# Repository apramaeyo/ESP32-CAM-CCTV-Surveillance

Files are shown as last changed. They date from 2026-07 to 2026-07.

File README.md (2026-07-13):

# ESP32-CAM-CCTV-Surveillance
Dual-axis pan/tilt CCTV system with live MJPEG streaming, night vision, motion detection and web control - built on ESP32-CAM

## Features

- Live MJPEG streaming
- Pan/Tilt camera control
- Auto patrol mode
- Software motion detection
- Automatic IR night vision
- Battery powered
- Custom PCB
- 3D printed casing

## Hardware

- ESP32-CAM
- MG90S Servos
- LDR
- 850/940nm IR LEDs
- 2×18650 Battery
- DC-DC Buck converter
- ESP32 CAM MB/FTDI MODULE

## Software

- Arduino IDE
- C/C++
- HTML/CSS/JavaScript

## Demo videos (click to view)

ESP32-CAM CCTV Demo 1 (https://youtu.be/uphCyD1VkAQ)

ESP32-CAM CCTV Demo 2 (https://youtu.be/F1fGy5tqCIQ)

ESP32-CAM CCTV Demo 3 (https://youtu.be/pY-STUEJHV8)

ESP32-CAM CCTV Demo 4 (https://youtu.be/E-zW0o_Lmso)

### Finished Project

Finished Project

### Live Web Interface

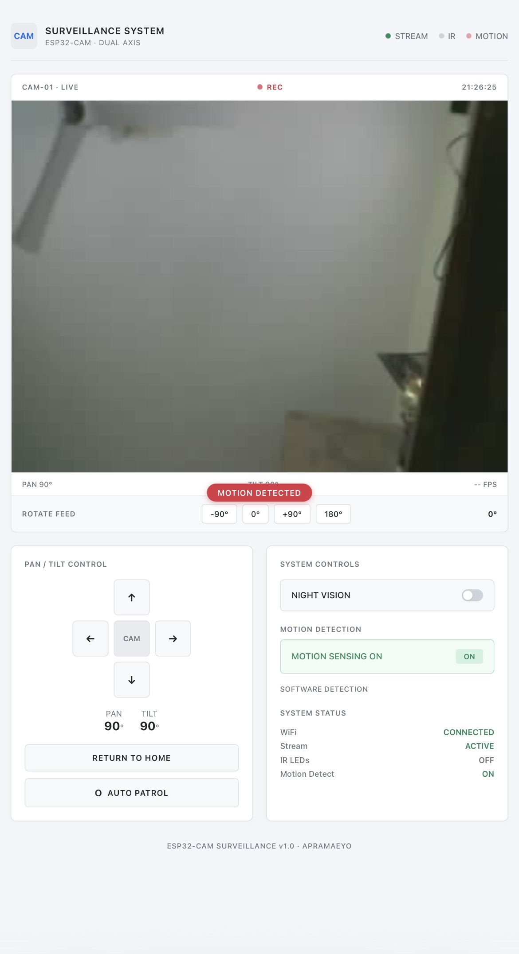
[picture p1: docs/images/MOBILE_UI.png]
Web UI


### PCB Design

PCB

### Night Vision Circuit

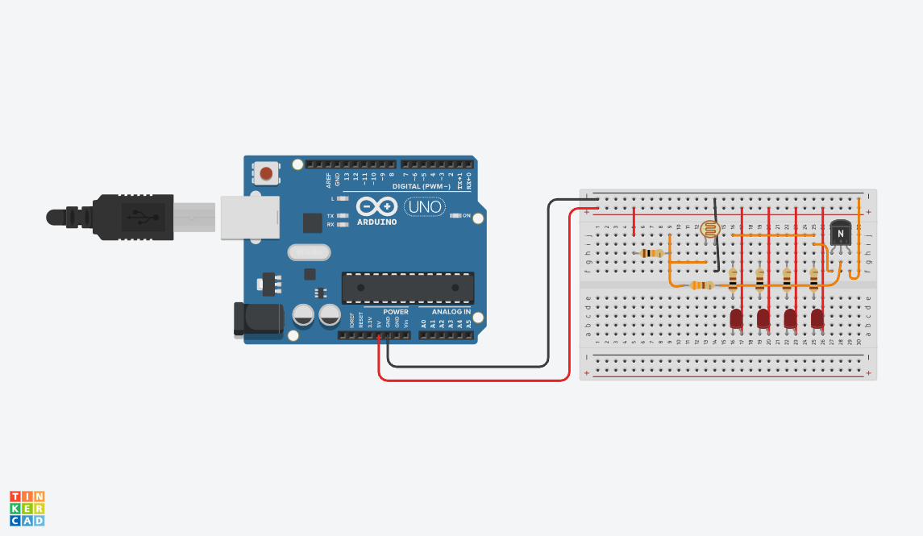
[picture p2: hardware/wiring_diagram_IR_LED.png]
Night Vision


## Future Improvements

- Telegram notifications
- Face detection
- Mobile application
- Cloud recording

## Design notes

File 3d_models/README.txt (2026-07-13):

ESP32CAM PANTILT CASE by Shubhayu15k on Thingiverse: https://www.thingiverse.com/thing:6805012

Summary:
This custom-designed case is perfect for housing your ESP32-CAM with a pan and tilt mechanism. Built for makers and hobbyists, this compact case ensures protection and stability for your camera module while allowing full range of motion with servo-controlled panning and tilting. Ideal for surveillance, robotics, or any project requiring camera movement, the case offers easy access to wiring and mounting points for servos.Key Features:Compact Design: Fits the ESP32-CAM module snugly.Servo Compatibility: Supports most micro servos for pan and tilt control.Ventilation Slots: Prevents overheating during extended use.Easy Assembly: Snap-fit design with screws for secure closure.Customizable Mounting: Features multiple holes for flexible mounting options.Clean Aesthetics: Sleek design that blends well with any project setup.This 3D-printed case makes your ESP32-CAM project more durable and organized, ensuring smooth camera operation in a range of applications!

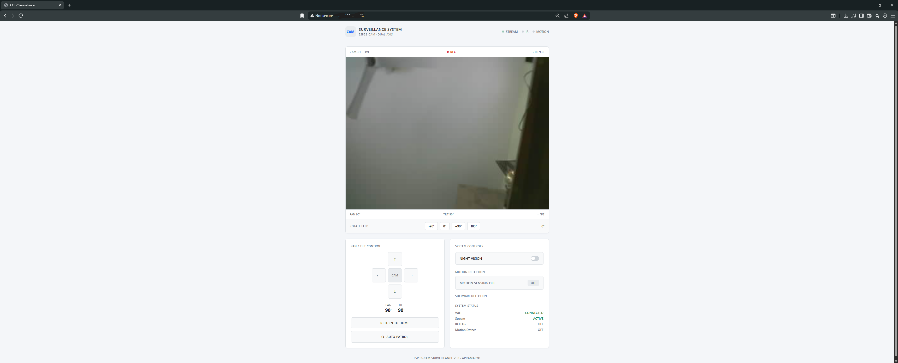
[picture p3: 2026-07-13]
docs/images/WEB_UI.png

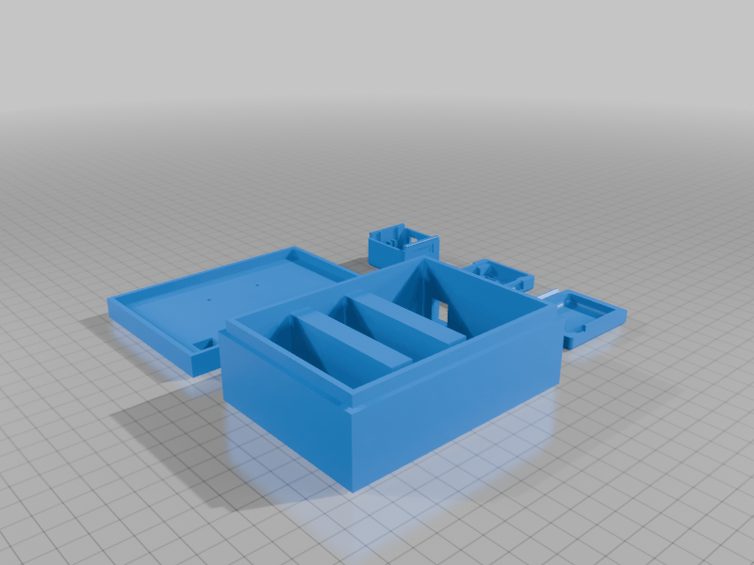
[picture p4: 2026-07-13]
3d_models/boxfinalesp32cam.png

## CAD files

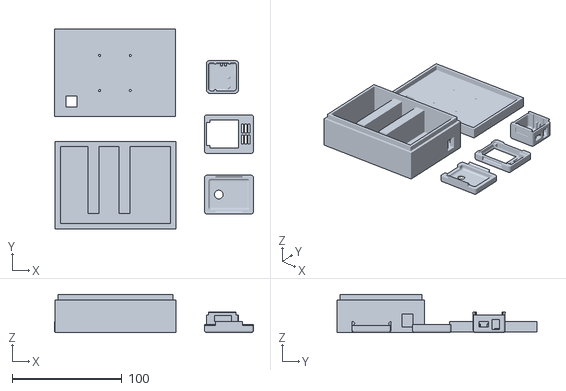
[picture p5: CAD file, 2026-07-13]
3d_models/boxfinalesp32cam.stl
181.1 x 181.9 x 35.0

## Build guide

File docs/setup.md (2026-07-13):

# Setup Guide — ESP32-CAM Dual-Axis CCTV Surveillance System

## Table of Contents

1. [Hardware Required](#hardware-required)
2. [Wiring](#wiring)
3. [Software Setup](#software-setup)
4. [Configuration](#configuration)
5. [Flashing](#flashing)
6. [Usage](#usage)
7. [3D Printing](#3d-printing)
8. [PCB](#pcb)
9. [Troubleshooting](#troubleshooting)

\---

## Hardware Required

|Component|Qty|Notes|
|-|-|-|
|AI Thinker ESP32-CAM (OV3660)|1|Main controller + camera|
|MG90S Metal Gear Servo|2|Pan + Tilt|
|Pan-Tilt Bracket|1|Standard SG90/MG90S compatible|
|HC-SR501 PIR Sensor|1|Optional — for hardware motion detect|
|850/940nm IR LED 5mm|4|Night vision|
|LDR (Light Dependent Resistor)|1|Auto night vision switching|
|2N2222A NPN Transistor (TO-92)|1|IR LED switching|
|330Ω Resistor 1/4W|1|Transistor base resistor|
|100Ω Resistor 1/4W|4|IR LED current limiters|
|10kΩ Resistor 1/4W|1|LDR voltage divider|
|LM2596S Buck Converter|1|Set output to 5V|
|18650 Battery Holder (2 cell)|1|With ON/OFF switch|
|18650 Battery 3.7V|2|Recommended: 2600mAh+|
|FTDI FT232RL / ESP32-CAM-MB|1|For flashing only|
|Jumper Wires|—|Male-to-female|
|Zero PCB / Perfboard|1|For IR LED circuit|

\---

## Wiring

### Power

```
18650 Pack (+) → LM2596S IN+
18650 Pack (−) → LM2596S IN−
LM2596S OUT+    → ESP32-CAM 5V
LM2596S OUT+    → Pan servo VCC 
LM2596S OUT+    → Tilt servo VCC 
LM2596S OUT−    → ESP32-CAM GND
LM2596S OUT−    → Pan servo GND 
LM2596S OUT−    → Tilt servo GND 
```

> ⚠️ Set LM2596S output to exactly 5.0V before connecting anything

### Servos

```
Pan  servo signal  → GPIO 14
Tilt servo signal  → GPIO 15
```

### IR LED Circuit (LDR auto-switching)

```
5V ──[10kΩ]──┬──[330Ω]──→ 2N2222 BASE (middle leg)
             │
           [LDR]
             │
            GND

2N2222 EMITTER (left leg)    → GND
2N2222 COLLECTOR (right leg) → 4× [100Ω] → IR LED (+)
                                             IR LED (−) → GND
```

### 2N2222 Pinout (flat face toward you, legs down)

```
Left = Emitter | Middle = Base | Right = Collector
```

### GPIO Summary

```
GPIO 4  → IR LED / Onboard flash LED
GPIO 14 → Pan servo signal
GPIO 15 → Tilt servo signal
```

\---

## Software Setup

### 1\. Install Arduino IDE

Download from [arduino.cc](https://www.arduino.cc/en/software)

### 2\. Add ESP32 Board Support

* Open Arduino IDE
* Go to **File → Preferences**
* Add to Additional Board Manager URLs:

```
https://dl.espressif.com/dl/package_esp32_index.json
```

* Go to **Tools → Board → Boards Manager**
* Search `esp32` → Install **esp32 by Espressif Systems**

### 3\. Install Libraries

Go to **Sketch → Include Library → Manage Libraries**

|Library|Author|
|-|-|
|ESP32Servo|Kevin Harrington|

### 4\. Select Board

**Tools → Board → AI Thinker ESP32-CAM**

\---

## Configuration

Open `firmware/ESP32_CAM_Surveillance.ino` and edit these lines at the top:

```cpp
// WiFi credentials
const char* WIFI_SSID = "YOUR_WIFI_NAME";
const char* WIFI_PASS = "YOUR_WIFI_PASSWORD";

// Static IP — change to match your network
// Find your gateway: Windows CMD → ipconfig → Default Gateway
IPAddress STATIC_IP(192, 168, 1, 100);  // ← pick any free IP
IPAddress GATEWAY  (192, 168, 1,   1);  // ← your router IP
IPAddress SUBNET   (255, 255, 255,  0);  // ← leave this
IPAddress DNS      (  8,   8,   8,  8);  // ← leave this
```

> Example: if your gateway is 192.168.108.1 → use 192.168.108.150 for STATIC_IP

\---

## Flashing

### Using FTDI Module

```
FTDI GND → ESP32-CAM GND
FTDI 5V  → ESP32-CAM 5V
FTDI TX  → ESP32-CAM U0R
FTDI RX  → ESP32-CAM U0T
GPIO 0   → GND  (boot mode — only during flashing)
```

1. Connect GPIO 0 to GND
2. Power on
3. Click Upload in Arduino IDE
4. When you see `Connecting......` — press RESET button on ESP32-CAM
5. After upload — disconnect GPIO 0 from GND
6. Press RESET
7. Open Serial Monitor at **115200 baud**
8. You will see:

```
━━━━━━━━━━━━━━━━━━━━━━━━━━━━━━━━━━━
  BOOKMARK THIS URL: http://192.168.1.100
  This IP will NEVER change.
━━━━━━━━━━━━━━━━━━━━━━━━━━━━━━━━━━━
```

### Using ESP32-CAM-MB

Just plug in via USB — no extra wiring needed. GPIO 0 handled automatically.

\---

## Usage

Open the IP address in any browser on the same WiFi network.

### Web UI Features

|Button|Function|
|-|-|
|▲ ▼ ◀ ▶|Pan and tilt camera|
|⌂ RETURN TO HOME|Snap back to 90°/90°|
|↻ AUTO PATROL|Continuous left-right sweep|
|NIGHT VISION|Toggle IR LED/inbuilt LED (GPIO 4)|
|MOTION DETECT|Enable/disable software motion detection|
|↺ ⊙ ↻ ↕|Rotate live feed 90°/180°/270° in browser|

### Motion Detection

When motion is detected:

* MOTION DETECTED banner appears on live feed
* Red dot pulses in header
* Clears automatically after 3 seconds of no motion

### Night Vision

* Manual: press button on web UI
* Automatic (if LDR circuit installed): hardware controlled, no button needed

\---

## 3D Printing

Files in `3d_models` folder.

### Print Settings

```
Material : PLA
Layer    : 0.2mm
Infill   : 25-30%
Walls    : 3-4 perimeters
Supports : Yes for elec_base only
```

\---

## Troubleshooting

|Problem|Cause|Fix|
|-|-|-|
|Stream not loading|Wrong IP or not on same WiFi|Check Serial Monitor for IP|
|Camera init failed|Bad 5V supply or loose ribbon|Check LM2596S output = 5V, reseat ribbon|
|Servos jitter|Insufficient current|Connect servo power direct to LM2596S, not through breadboard|
|Only one servo moves|Wrong GPIO|Confirm GPIO 14 = pan, GPIO 15 = tilt|
|IR LED not glowing|2N2222 orientation wrong|Flat face toward you: left=E, mid=B, right=C|
|No WiFi connection|Wrong credentials or 5GHz network|ESP32 only supports 2.4GHz|
|Website laggy|WiFi power saving enabled|Already disabled in firmware — check router distance|
|Motion too sensitive|Lighting changes triggering|Increase `MOTION_THRESHOLD` value in code|
|IP keeps changing|DHCP reassigning|Static IP already configured — check GATEWAY matches your router|

\---

## License

MIT License — free to use, modify, and distribute with attribution.

\---

*Built by Apramaeyo*

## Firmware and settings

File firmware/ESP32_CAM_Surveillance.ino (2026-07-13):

/*
 * ============================================================
 *  Dual-Axis CCTV Surveillance System
 *  Hardware : ESP32-CAM (AI Thinker)
 *  Features : Live MJPEG stream, Pan/Tilt servos,
 *             Motion detection, IR LED night vision
 *  Control  : Web browser over WiFi
 * ============================================================
 *
 *  WIRING SUMMARY
 *  ──────────────
 *  Pan  Servo  signal → GPIO 14   
 *  Tilt Servo  signal → GPIO 15   
 *  Both Servo  VCC   → 5V rail from buck converter
 *  Both Servo  GND   → Common GND
 *
 *  IR LED circuit:
 *    GPIO 4 → 330Ω resistor → Base of 2N2222
 *    Collector → IR LED anode
 *    IR LED cathode → GND
 *    Emitter → GND
 *  (GPIO 4 is also the onboard white flash LED — it will light
 *   up instead if you don't have IR LEDs yet, useful for testing)
 *
 *  Power:
 *    18650 pack → LM2596S → 5V → ESP32-CAM 5V pin + Servo VCC
 *    Common GND between all components
 *
 *  FLASHING INSTRUCTIONS
 *  ─────────────────────
 *  1. Install board: "AI Thinker ESP32-CAM" in Arduino IDE
 *     (add https://dl.espressif.com/dl/package_esp32_index.json
 *      to Preferences → Additional board manager URLs)
 *  2. Install library: ESP32Servo (by Kevin Harrington)
 *  3. Connect GPIO 0 to GND before powering on (boot mode)
 *  4. Select: Tools → Board → AI Thinker ESP32-CAM
 *             Tools → Port → your COM port
 *  5. Upload, then disconnect GPIO 0 from GND, press RESET
 *  6. Open Serial Monitor at 115200 baud to see the IP address
 *  7. Open that IP in your browser
 * ============================================================
 */

#include "esp_camera.h"
#include <WiFi.h>
#include <WebServer.h>
#include <ESP32Servo.h>
#include "esp_wifi.h"       // for esp_wifi_set_ps()

// ─── WiFi credentials ────────────────────────────────────────
const char* WIFI_SSID = "WIFISSID";
const char* WIFI_PASS = "WIFIPASSWORD";

// ─── Static IP configuration ─────────────────────────────────
// Change these to match your home network.
// STATIC_IP  = the fixed address you want ESP32-CAM to always use
// GATEWAY    = your router IP (usually 192.168.1.1 or 192.168.0.1)
// SUBNET     = almost always 255.255.255.0
//
// HOW TO FIND YOUR GATEWAY:
//   Windows: open CMD → type "ipconfig" → look for "Default Gateway"
//   Android: WiFi settings → tap network → Gateway
//   After finding gateway, set STATIC_IP to same first 3 numbers
//   e.g. gateway = 192.168.1.1  →  use 192.168.1.XXX for static IP
//   Pick XXX between 100-200 to avoid conflicts with other devices
//
IPAddress STATIC_IP(192, 168, 1, XX);   // ← your chosen fixed IP
IPAddress GATEWAY  (192,168,1,XX);   // ← your router IP
IPAddress SUBNET   (255, 255, 255, 0);   // ← leave this as is
IPAddress DNS      (8,   8,   8,   8);   // ← Google DNS, leave as is

// ─── Pin definitions ─────────────────────────────────────────
#define PAN_PIN   14   // Pan servo signal
#define TILT_PIN  15   // Tilt servo signal
#define IR_PIN     4   // GPIO 4 = onboard white flash LED

// ─── Servo angle limits ──────────────────────────────────────
#define PAN_MIN   0
#define PAN_MAX   180
#define PAN_HOME  90
#define TILT_MIN  90
#define TILT_MAX  180
#define TILT_HOME 90
#define STEP      15    // target degrees per button press

// ─── Smooth servo motion config ──────────────────────────────
// Servos move via easing — accelerate, cruise, decelerate
// like a real camera gimbal. No more sudden jumps.
float panCurrent   = 90.0;   // actual current position (float for smooth steps)
float tiltCurrent  = 90.0;
float panTarget    = 90.0;   // where we want to go
float tiltTarget   = 90.0;
const float EASE_SPEED   = 0.10;  // 0.0-1.0: higher = faster/snappier
                                   // 0.10 = very smooth/slow
                                   // 0.18 = smooth but responsive  
                                   // 0.30 = fast, slight smoothing
                                   // 1.0  = instant (no easing)
const float DEAD_ZONE    = 0.4;   // stop moving when this close to target (degrees)

// ─── AI Thinker ESP32-CAM pins (OV3660 sensor variant) ──────
#define PWDN_GPIO_NUM     32
#define RESET_GPIO_NUM    -1
#define XCLK_GPIO_NUM      0
#define SIOD_GPIO_NUM     26
#define SIOC_GPIO_NUM     27
#define Y9_GPIO_NUM       35
#define Y8_GPIO_NUM       34
#define Y7_GPIO_NUM       39
#define Y6_GPIO_NUM       36
#define Y5_GPIO_NUM       21
#define Y4_GPIO_NUM       19
#define Y3_GPIO_NUM       18
#define Y2_GPIO_NUM        5
#define VSYNC_GPIO_NUM    25
#define HREF_GPIO_NUM     23
#define PCLK_GPIO_NUM     22

// ─── Global state ────────────────────────────────────────────
Servo panServo;
Servo tiltServo;
WebServer server(80);

// panAngle/tiltAngle now track TARGET (int for JSON/display)
// Actual smooth position tracked by panCurrent/tiltCurrent (float)
int panAngle  = PAN_HOME;
int tiltAngle = TILT_HOME;
bool irOn          = false;
bool motionDetected = false;

// Software motion detection — frame differencing
uint8_t* prevFrame = nullptr;
const int MOTION_THRESHOLD = 40;   // pixel difference to count
const int MOTION_PIXELS    = 500;  // how many changed pixels = motion

// ─── Embedded Web UI ─────────────────────────────────────────
const char HTML_PAGE[] PROGMEM = R"rawhtml(
<!DOCTYPE html>
<html lang="en">
<head>
<meta charset="UTF-8">
<meta name="viewport" content="width=device-width, initial-scale=1.0">
<title>CCTV Surveillance</title>
<style>
  :root {
    --bg: #f4f6f9;
    --panel: #ffffff;
    --border: #dee2e6;
    --accent: #0d6efd;
    --accent-hover: #0b5ed7;
    --text: #212529;
    --text-dim: #6c757d;
    --green: #198754;
    --red: #dc3545;
  }
  
  * { box-sizing: border-box; margin: 0; padding: 0; }
  
  body {
    background: var(--bg);
    color: var(--text);
    font-family: -apple-system, BlinkMacSystemFont, "Segoe UI", Roboto, Helvetica, Arial, sans-serif;
    min-height: 100vh;
    display: flex;
    flex-direction: column;
    align-items: center;
    padding: 20px 16px;
    gap: 20px;
  }

  /* ── Header ── */
  header {
    width: 100%;
    max-width: 780px;
    display: flex;
    align-items: center;
    justify-content: space-between;
    border-bottom: 1px solid var(--border);
    padding-bottom: 16px;
  }
  .logo {
    display: flex;
    align-items: center;
    gap: 12px;
  }
  .logo-icon {
    width: 40px; height: 40px;
    background: #e9ecef;
    border-radius: 8px;
    display: flex; align-items: center; justify-content: center;
    font-size: 13px;
    font-weight: 700;
    color: var(--accent);
  }
  .logo-text { font-size: 14px; font-weight: 600; letter-spacing: 0.05em; color: var(--text); }
  .logo-sub  { font-size: 11px; color: var(--text-dim); letter-spacing: 0.05em; margin-top: 2px;}
  .status-bar {
    display: flex; gap: 16px; font-size: 12px; font-weight: 500; color: var(--text-dim);
  }
  .status-item { display: flex; align-items: center; gap: 6px; }
  .dot {
    width: 8px; height: 8px; border-radius: 50%;
    background: var(--green);
    animation: pulse 2s infinite;
  }
  .dot.off { background: #ced4da; animation: none; }
  .dot.alert { background: var(--red); }
  @keyframes pulse {
    0%,100% { opacity: 1; } 50% { opacity: 0.4; }
  }

  /* ── Stream panel ── */
  .stream-panel {
    width: 100%;
    max-width: 780px;
    background: var(--panel);
    border: 1px solid var(--border);
    border-radius: 8px;
    overflow: hidden;
    position: relative;
    box-shadow: 0 2px 4px rgba(0,0,0,0.02);
  }
  .stream-header {
    display: flex;
    justify-content: space-between;
    align-items: center;
    padding: 12px 16px;
    border-bottom: 1px solid var(--border);
    font-size: 11px;
    font-weight: 600;
    letter-spacing: 0.05em;
    color: var(--text-dim);
  }
  .rec-badge {
    display: flex; align-items: center; gap: 6px;
    color: var(--red); font-weight: 700;
  }
  .rec-dot {
    width: 8px; height: 8px; border-radius: 50%;
    background: var(--red);
    animation: pulse 1s infinite;
  }
  
  .motion-overlay {
    position: absolute;
    bottom: 45px; left: 0; right: 0;
    display: flex; justify-content: center;
    pointer-events: none;
  }
  .motion-badge {
    background: var(--red);
    color: #fff;
    padding: 6px 16px;
    border-radius: 20px;
    font-size: 12px;
    font-weight: 600;
    letter-spacing: 0.05em;
    display: none;
    box-shadow: 0 2px 8px rgba(220, 53, 69, 0.4);
  }
  .motion-badge.visible { display: block; }
  .stream-footer {
    padding: 10px 16px;
    display: flex; justify-content: space-between;
    font-size: 11px; font-weight: 500; color: var(--text-dim);
    border-top: 1px solid var(--border);
  }

  /* ── Controls ── */
  .controls-row {
    width: 100%;
    max-width: 780px;
    display: flex;
    gap: 20px;
    flex-wrap: wrap;
  }
  .ctrl-panel {
    background: var(--panel);
    border: 1px solid var(--border);
    border-radius: 8px;
    padding: 20px;
    flex: 1;
    min-width: 280px;
    box-shadow: 0 2px 4px rgba(0,0,0,0.02);
  }
  .ctrl-label {
    font-size: 11px;
    font-weight: 600;
    letter-spacing: 0.05em;
    color: var(--text-dim);
    margin-bottom: 16px;
    text-transform: uppercase;
  }

  /* D-pad */
  .dpad {
    display: grid;
    grid-template-columns: repeat(3, 54px);
    grid-template-rows: repeat(3, 54px);
    gap: 8px;
    justify-content: center;
  }
  .dpad-btn {
    background: #f8f9fa;
    border: 1px solid var(--border);
    border-radius: 6px;
    color: var(--text);
    font-size: 16px;
    font-weight: bold;
    cursor: pointer;
    display: flex; align-items: center; justify-content: center;
    transition: all 0.15s ease;
    user-select: none;
    -webkit-tap-highlight-color: transparent;
  }
  .dpad-btn:hover {
    background: #e9ecef;
  }
  .dpad-btn:active, .dpad-btn.pressed {
    background: #dde2e6;
    transform: scale(0.95);
  }
  .dpad-center {
    background: #e9ecef;
    color: var(--text-dim);
    font-size: 11px;
    font-weight: 600;
    cursor: default;
  }
  .dpad-center:active { transform: none; }

  /* Angle readout */
  .angle-display {
    margin-top: 16px;
    display: flex; justify-content: center; gap: 24px;
    font-size: 12px; color: var(--text-dim);
    text-align: center;
  }
  .angle-val { color: var(--text); font-size: 18px; font-weight: 700; }

  /* Toggle buttons */
  .toggle-group {
    display: flex; flex-direction: column; gap: 12px;
  }

  .toggle-btn {
    background: #f8f9fa;
    border: 1px solid var(--border);
    border-radius: 6px;
    color: var(--text);
    padding: 14px 16px;
    cursor: pointer;
    font-family: inherit;
    font-size: 13px;
    font-weight: 500;
    display: flex; align-items: center; justify-content: space-between;
    transition: all 0.2s ease;
  }
  .toggle-btn:hover { border-color: var(--accent); }
  .toggle-btn.active {
    border-color: var(--accent);
    background: #f0f7ff;
    color: var(--accent);
  }
  .toggle-indicator {
    width: 32px; height: 18px;
    background: #ced4da;
    border-radius: 10px;
    position: relative;
    transition: background 0.2s;
  }
  .toggle-indicator::after {
    content: '';
    position: absolute;
    width: 14px; height: 14px;
    border-radius: 50%;
    background: #fff;
    top: 2px; left: 2px;
    transition: transform 0.2s, background 0.2s;
    box-shadow: 0 1px 3px rgba(0,0,0,0.1);
  }
  .toggle-btn.active .toggle-indicator { background: var(--accent); }
  .toggle-btn.active .toggle-indicator::after {
    transform: translateX(14px);
  }

  /* ── Big Motion Detect Button ── */
  .motion-ctrl-wrap {
    margin-top: 20px;
    display: flex;
    flex-direction: column;
    gap: 8px;
  }
  .motion-ctrl-label {
    font-size: 11px;
    font-weight: 600;
    letter-spacing: 0.05em;
    color: var(--text-dim);
    text-transform: uppercase;
  }
  .motion-big-btn {
    width: 100%;
    border: none;
    border-radius: 6px;
    cursor: pointer;
    font-family: inherit;
    padding: 0;
    overflow: hidden;
    position: relative;
    transition: transform 0.1s;
    outline: none;
  }
  .motion-big-btn:active { transform: scale(0.98); }

  /* Inner layout */
  .motion-btn-inner {
    display: flex;
    align-items: center;
    justify-content: space-between;
    padding: 14px 16px;
    transition: all 0.3s ease;
    border: 1px solid transparent;
    border-radius: 6px;
  }

  /* OFF state */
  .motion-big-btn.off .motion-btn-inner {
    background: #f8f9fa;
    border-color: var(--border);
  }
  .motion-big-btn.off .motion-btn-text  { color: var(--text-dim); font-size: 13px; font-weight: 500; }
  .motion-big-btn.off .motion-btn-state {
    background: #e9ecef;
    color: var(--text-dim);
    font-size: 11px;
    font-weight: 600;
    padding: 4px 12px;
    border-radius: 4px;
  }

  /* ON state */
  .motion-big-btn.on .motion-btn-inner {
    background: #f0fdf4;
    border-color: #a3e6cd;
  }
  .motion-big-btn.on .motion-btn-text  { color: var(--green); font-size: 13px; font-weight: 500; }
  .motion-big-btn.on .motion-btn-state {
    background: #d1f2e2;
    color: var(--green);
    font-size: 11px;
    font-weight: 600;
    padding: 4px 12px;
    border-radius: 4px;
  }

  /* Confirm flash overlay */
  .motion-big-btn::after {
    content: '';
    position: absolute;
    inset: 0;
    background: rgba(0,0,0,0.05);
    opacity: 0;
    pointer-events: none;
    transition: opacity 0.15s;
  }
  .motion-big-btn.flash::after { opacity: 1; }

  /* Sensitivity slider */
  .sensitivity-row {
    display: flex;
    align-items: center;
    gap: 12px;
    padding: 8px 4px 4px;
    opacity: 1;
    transition: opacity 0.3s;
  }
  .sensitivity-row.hidden { opacity: 0.3; pointer-events: none; }
  .sens-label { font-size: 12px; font-weight: 500; color: var(--text-dim); white-space: nowrap; }
  .sens-slider {
    flex: 1;
    -webkit-appearance: none;
    height: 4px;
    border-radius: 2px;
    background: #e9ecef;
    outline: none;
    cursor: pointer;
  }
  .sens-slider::-webkit-slider-thumb {
    -webkit-appearance: none;
    width: 16px; height: 16px;
    border-radius: 50%;
    background: var(--accent);
    cursor: pointer;
    transition: background 0.2s;
  }
  .sens-slider::-webkit-slider-thumb:hover { background: var(--accent-hover); }
  .sens-val {
    font-size: 12px;
    font-weight: 600;
    color: var(--text);
    min-width: 24px;
    text-align: right;
  }

  /* Home button */
  .home-btn {
    width: 100%;
    background: #f8f9fa;
    border: 1px solid var(--border);
    border-radius: 6px;
    color: var(--text);
    padding: 12px;
    cursor: pointer;
    font-family: inherit;
    font-size: 12px;
    font-weight: 600;
    letter-spacing: 0.05em;
    margin-top: 16px;
    transition: all 0.2s ease;
  }
  .home-btn:hover { border-color: var(--accent); color: var(--accent); background: #f0f7ff; }

  /* Rotate / patrol button */
  .rotate-btn {
    width: 100%;
    border-radius: 6px;
    padding: 12px;
    cursor: pointer;
    font-family: inherit;
    font-size: 12px;
    font-weight: 600;
    letter-spacing: 0.05em;
    margin-top: 10px;
    border: 1px solid var(--border);
    background: #f8f9fa;
    color: var(--text);
    display: flex;
    align-items: center;
    justify-content: center;
    gap: 8px;
    transition: all 0.2s ease;
  }
  .rotate-btn.spinning {
    border-color: var(--accent);
    color: var(--accent);
    background: #f0f7ff;
  }
  .spin-icon {
    display: inline-block;
    transition: transform 0.3s;
    font-size: 14px;
  }
  .rotate-btn.spinning .spin-icon {
    animation: spinIcon 1.5s linear infinite;
  }
  @keyframes spinIcon {
    from { transform: rotate(0deg); }
    to   { transform: rotate(360deg); }
  }

  /* Stream image rotation */
  .stream-img {
    width: 100%;
    display: block;
    aspect-ratio: 4/3;
    object-fit: cover;
    background: #e9ecef;
    transition: transform 0.4s cubic-bezier(0.4, 0, 0.2, 1);
    transform-origin: center center;
  }
  .stream-img.rot90  { transform: rotate(90deg)  scale(0.75); }
  .stream-img.rot180 { transform: rotate(180deg) scale(1.0);  }
  .stream-img.rot270 { transform: rotate(270deg) scale(0.75); }

  /* Rotate feed button row */
  .feed-rotate-row {
    display: flex;
    align-items: center;
    justify-content: space-between;
    padding: 12px 16px;
    border-top: 1px solid var(--border);
    background: #f8f9fa;
  }
  .feed-rotate-label {
    font-size: 11px;
    font-weight: 600;
    letter-spacing: 0.05em;
    color: var(--text-dim);
  }
  .feed-rotate-btns {
    display: flex;
    gap: 8px;
  }
  .feed-rot-btn {
    background: #ffffff;
    border: 1px solid var(--border);
    border-radius: 4px;
    color: var(--text);
    padding: 6px 12px;
    font-size: 12px;
    font-weight: 500;
    cursor: pointer;
    transition: all 0.15s ease;
    font-family: inherit;
  }
  .feed-rot-btn:hover  { border-color: var(--accent); color: var(--accent); }
  .feed-rot-btn:active { background: #e9ecef; transform: scale(0.95); }
  .feed-rot-btn.active { border-color: var(--accent); color: var(--accent); background: #f0f7ff; font-weight: 600;}
  .rot-angle-badge {
    font-size: 12px;
    font-weight: 600;
    color: var(--text);
    min-width: 30px;
    text-align: right;
  }

  /* Footer */
  footer {
    font-size: 11px;
    font-weight: 500;
    color: var(--text-dim);
    letter-spacing: 0.05em;
    margin-top: 10px;
  }

  @media (max-width: 520px) {
    .status-bar { display: none; }
  }
</style>
</head>
<body>

<header>
  <div class="logo">
    <div class="logo-icon">CAM</div>
    <div>
      <div class="logo-text">SURVEILLANCE SYSTEM</div>
      <div class="logo-sub">ESP32-CAM · DUAL AXIS</div>
    </div>
  </div>
  <div class="status-bar">
    <div class="status-item"><div class="dot" id="streamDot"></div>STREAM</div>
    <div class="status-item"><div class="dot off" id="irDot"></div>IR</div>
    <div class="status-item"><div class="dot off" id="motionDot"></div>MOTION</div>
  </div>
</header>

<!-- Stream -->
<div class="stream-panel">
  <div class="stream-header">
    <span>CAM-01 · LIVE</span>
    <div class="rec-badge"><div class="rec-dot"></div>REC</div>
    <span id="timeDisplay">--:--:--</span>
  </div>
  <img class="stream-img" id="streamImg" src="/stream" alt="Live Feed">
  <div class="motion-overlay">
    <div class="motion-badge" id="motionBadge">MOTION DETECTED</div>
  </div>
  <div class="stream-footer">
    <span>PAN <span id="panReadout">90</span>°</span>
    <span>TILT <span id="tiltReadout">90</span>°</span>
    <span id="fpsDisplay">-- FPS</span>
  </div>
  <div class="feed-rotate-row">
    <span class="feed-rotate-label">ROTATE FEED</span>
    <div class="feed-rotate-btns">
      <button class="feed-rot-btn" onclick="rotateFeed(-90)" title="Rotate left 90°">-90°</button>
      <button class="feed-rot-btn" onclick="rotateFeed(0)"   title="Reset rotation" id="rotResetBtn">0°</button>
      <button class="feed-rot-btn" onclick="rotateFeed(90)"  title="Rotate right 90°">+90°</button>
      <button class="feed-rot-btn" onclick="rotateFeed(180)" title="Flip 180°">180°</button>
    </div>
    <span class="rot-angle-badge" id="rotBadge">0°</span>
  </div>
</div>

<!-- Controls -->
<div class="controls-row">

  <!-- D-pad -->
  <div class="ctrl-panel">
    <div class="ctrl-label">PAN / TILT CONTROL</div>
    <div class="dpad">
      <div></div>
      <div class="dpad-btn" onclick="move('up')"    id="btn-up">↑</div>
      <div></div>
      <div class="dpad-btn" onclick="move('left')"  id="btn-left">←</div>
      <div class="dpad-btn dpad-center">CAM</div>
      <div class="dpad-btn" onclick="move('right')" id="btn-right">→</div>
      <div></div>
      <div class="dpad-btn" onclick="move('down')"  id="btn-down">↓</div>
      <div></div>
    </div>
    <div class="angle-display">
      <div>PAN <br><span class="angle-val" id="panAngle">90</span>°</div>
      <div>TILT<br><span class="angle-val" id="tiltAngle">90</span>°</div>
    </div>
    <button class="home-btn" onclick="goHome()">RETURN TO HOME</button>
    <button class="rotate-btn" id="rotateBtn" onclick="togglePatrol()">
      <span class="spin-icon">O</span>
      <span id="rotateBtnText">AUTO PATROL</span>
    </button>
  </div>

  <!-- Toggles -->
  <div class="ctrl-panel">
    <div class="ctrl-label">SYSTEM CONTROLS</div>
    <div class="toggle-group">

      <button class="toggle-btn" id="irBtn" onclick="toggleIR()">
        <span>NIGHT VISION</span>
        <div class="toggle-indicator"></div>
      </button>

    </div>

    <!-- Big Motion Detect Button -->
    <div class="motion-ctrl-wrap">
      <div class="motion-ctrl-label">MOTION DETECTION</div>

      <button class="motion-big-btn on" id="motionBtn" onclick="toggleMotion()">
        <div class="motion-btn-inner">
          <span class="motion-btn-text" id="motionBtnText">MOTION SENSING ON</span>
          <span class="motion-btn-state" id="motionBtnState">ON</span>
        </div>
      </button>

      <!-- PIR sensor -->
      <div style="font-size:11px; font-weight:500; color:var(--text-dim); margin-top:8px; letter-spacing:0.02em;">
        SOFTWARE DETECTION
      </div>
    </div>

    <div style="margin-top:20px; font-size:12px; font-weight:500; color:var(--text-dim); line-height:1.8;">
      <div style="font-weight:600; font-size: 11px; letter-spacing: 0.05em; margin-bottom: 8px;">SYSTEM STATUS</div>
      <div>
        WiFi <span style="float: right; font-weight: 600; color:var(--green)">CONNECTED</span><br>
        Stream <span style="float: right; font-weight: 600; color:var(--green)">ACTIVE</span><br>
        IR LEDs <span id="irStatus" style="float: right; font-weight: 600; color:var(--text-dim)">OFF</span><br>
        Motion Detect <span id="mdStatus" style="float: right; font-weight: 600; color:var(--green)">ON</span>
      </div>
    </div>
  </div>

</div>
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
void loop() {
  server.handleClient();
  smoothServoTick();
  patrolTick();

  delay(1);
}

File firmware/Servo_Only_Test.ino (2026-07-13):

/*
 * ============================================================
 *  SERVO MOTOR TEST — ESP32-CAM (AI Thinker)
 *  Tests pan + tilt MG90S servos ONLY
 *  No camera, no WiFi, no other components needed
 *
 *  MINIMUM WIRING TO RUN THIS:
 *
 *  Power (from LM2596S set to 5V):
 *    5V rail  →  ESP32-CAM 5V pin
 *    5V rail  →  Both servo VCC 
 *    GND rail →  ESP32-CAM GND pin
 *    GND rail →  Both servo GND 
 *
 *  Pan Servo (horizontal):
 *    Signal  → GPIO 14
 *
 *  Tilt Servo (vertical):
 *    Signal  → GPIO 15
 *
 *  LIBRARY NEEDED:
 *    ESP32Servo by Kevin Harrington
 *    Install via: Sketch → Include Library → Manage Libraries
 *    Search "ESP32Servo" → Install
 * ============================================================
 */

#include <ESP32Servo.h>

#define PAN_PIN   14
#define TILT_PIN  15

Servo panServo;
Servo tiltServo;

// ── Helper: move servo slowly step by step ──────────────────
void slowMove(Servo &servo, int fromAngle, int toAngle, int stepDelay = 15) {
  if (fromAngle < toAngle) {
    for (int a = fromAngle; a <= toAngle; a++) {
      servo.write(a);
      delay(stepDelay);
    }
  } else {
    for (int a = fromAngle; a >= toAngle; a--) {
      servo.write(a);
      delay(stepDelay);
    }
  }
}

void setup() {
  Serial.begin(115200);
  delay(1000);

  Serial.println();
  Serial.println("====================================");
  Serial.println("  SERVO TEST — ESP32-CAM");
  Serial.println("====================================");
  Serial.println();

  // Attach servos
  panServo.attach(PAN_PIN,   500, 2400);
  tiltServo.attach(TILT_PIN, 500, 2400);
  Serial.println("[OK] Servos attached");
  Serial.println("     Pan  → GPIO " + String(PAN_PIN));
  Serial.println("     Tilt → GPIO " + String(TILT_PIN));
  Serial.println();

  // ── TEST 1: Center both servos ──────────────────────────
  Serial.println("TEST 1 — CENTER (both to 90°)");
  panServo.write(90);
  tiltServo.write(90);
  Serial.println("  Both servos → 90° (home position)");
  Serial.println("  Both should be pointing straight ahead");
  delay(2000);

  // ── TEST 2: Pan servo only ──────────────────────────────
  Serial.println();
  Serial.println("TEST 2 — PAN SERVO ONLY (GPIO 14)");
  Serial.println("  Tilt stays at 90° — only pan moves");
  Serial.println();

  Serial.println("  Pan: 90° → 0° (full left)");
  slowMove(panServo, 90, 0);
  delay(800);

  Serial.println("  Pan: 0° → 180° (full right)");
  slowMove(panServo, 0, 180);
  delay(800);

  Serial.println("  Pan: 180° → 90° (back to center)");
  slowMove(panServo, 180, 90);
  delay(1000);

  Serial.println("  [CHECK] Did the pan servo sweep left then right?");
  Serial.println("  If YES → Pan servo working");
  Serial.println("  If NO  → Check GPIO 14 wiring and 5V power");

  delay(2000);

  // ── TEST 3: Tilt servo only ─────────────────────────────
  Serial.println();
  Serial.println("TEST 3 — TILT SERVO ONLY (GPIO 15)");
  Serial.println("  Pan stays at 90° — only tilt moves");
  Serial.println();

  Serial.println("  Tilt: 90° → 150° (tilt up)");
  slowMove(tiltServo, 90, 150);
  delay(800);

  Serial.println("  Tilt: 150° → 30° (tilt down)");
  slowMove(tiltServo, 150, 30);
  delay(800);

  Serial.println("  Tilt: 30° → 90° (back to center)");
  slowMove(tiltServo, 30, 90);
  delay(1000);

  Serial.println("  [CHECK] Did the tilt servo go up then down?");
  Serial.println("  If YES → Tilt servo working");
  Serial.println("  If NO  → Check GPIO 15 wiring and 5V power");

  delay(2000);

  // ── TEST 4: Both together ───────────────────────────────
  Serial.println();
  Serial.println("TEST 4 — BOTH SERVOS TOGETHER");

  Serial.println("  Moving to top-left corner...");
  panServo.write(0);
  tiltServo.write(150);
  delay(1500);

  Serial.println("  Moving to top-right corner...");
  panServo.write(180);
  tiltServo.write(150);
  delay(1500);

  Serial.println("  Moving to bottom-right corner...");
  panServo.write(180);
  tiltServo.write(30);
  delay(1500);

  Serial.println("  Moving to bottom-left corner...");
  panServo.write(0);
  tiltServo.write(30);
  delay(1500);

  Serial.println("  Returning to HOME...");
  panServo.write(90);
  tiltServo.write(90);
  delay(1500);

  // ── TEST 5: Nod and shake ───────────────────────────────
  Serial.println();
  Serial.println("TEST 5 — NOD (tilt) AND SHAKE (pan)");

  Serial.println("  Nodding 3 times (tilt up/down)...");
  for (int i = 0; i < 3; i++) {
    tiltServo.write(115);
    delay(300);
    tiltServo.write(65);
    delay(300);
  }
  tiltServo.write(90);
  delay(500);

  Serial.println("  Shaking 3 times (pan left/right)...");
  for (int i = 0; i < 3; i++) {
    panServo.write(60);
    delay(300);
    panServo.write(120);
    delay(300);
  }
  panServo.write(90);
  delay(500);

  // ── DONE ────────────────────────────────────────────────
  Serial.println();
  Serial.println("====================================");
  Serial.println("  ALL SERVO TESTS COMPLETE");
  Serial.println("====================================");
  Serial.println();
  Serial.println("Both servos now hold at 90° (home).");
  Serial.println();
  Serial.println("RESULTS:");
  Serial.println("  If pan moved  → GPIO 14 wiring correct");
  Serial.println("  If tilt moved → GPIO 15 wiring correct");
  Serial.println("  If neither moved:");
  Serial.println("    1. Check 5V on servo VCC (red) wires");
  Serial.println("    2. Check GND on servo GND (brown) wires");
  Serial.println("    3. Check signal wires on GPIO 14 and 15");
  Serial.println("    4. Confirm ESP32Servo library is installed");
  Serial.println();
  Serial.println("Type any letter + Enter in Serial Monitor");
  Serial.println("to run a single servo sweep again:");
  Serial.println("  p = pan sweep");
  Serial.println("  t = tilt sweep");
  Serial.println("  b = both corners");
  Serial.println("  h = go home (90/90)");
}
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
